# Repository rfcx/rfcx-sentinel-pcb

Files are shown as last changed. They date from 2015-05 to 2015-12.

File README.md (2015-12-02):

#RFCx Sentinel PCB
@gibsjose @jesse-millwood @rfcx

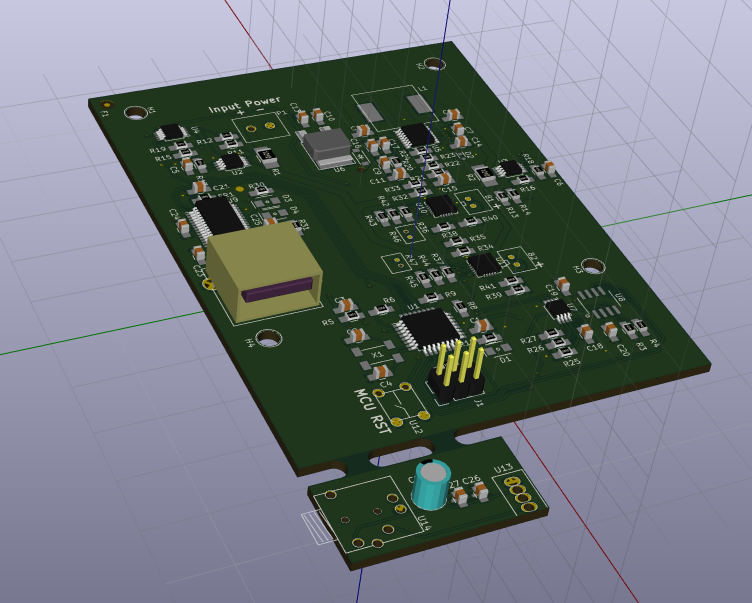
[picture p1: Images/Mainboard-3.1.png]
PCB


##Description
This repository contains the **KiCAD** project and related libraries for the RFCx PCB designed by Jesse Millwood and Joe Gibson for the GVSU (Grand Valley State University) RFCx Senior Project design, *Project Necromancer*. This project has been continued by Jesse Millwood and Joe Gibson after they graduated and has since been renamed *RFCx Sentinel*. 

This repository is for the main board that includes the following functionality:
- Buck/Boost input voltage to charge phone
- Regulate input power 3.3V to run the logic on the board
- Charge two Lithium Ion Batteries
- Take local measurements such as voltage, current, temperature, and humidity
- Relay information to the phone via a USB interface
- An experimental breakaway board for microphone filtering

This README is meant to be a user guide for the **REV 3** main board. 

###Revision Overview
Rev1 of the board was a single board and was designed for one particular off-the-shelf enclosure.
Rev2 of the design is a modular design in order to introduce a degree of flexibility to the design. This revision included an MPPT board and main board.
Rev3 of the design will keep the modular design, however new components will be chosen based on testing of Rev2. This revision is just the main board.

##Physical Install Instructions
The enclosure that is being used is the Polycase WP-33. The installer must take into consideration where the interfacing wires will be in relation to the other board. A list of interfacing wires that must be considered are:
* **Main Board:** Power from the panels.
* **Main Board:** 2 JST connectors that go from the batter charging circuitry to the batteries
* **Main Board:** 2 JST connectors that interface to the NTC thermocouple. This thermocouple is meant to be glued or attached to the batteries.
* **Main Board:** 1 USBA to microUSB connector to the phone
Once the hardware connections are made it will be a good idea to ensure that the phone has the proper software installed such as the proper ROM and version of the Gaurdian app. For phone software refer to the [RFCx Guardian App](https://github.com/rfcx/rfcx-guardian-android) github page.

##Outline of Directories
.  
├── Images  
│   ├── *Contains Images for the README*  
├── Kicad Project  
│   ├── Graphics  
│   │   ├── *Contains Graphics for the silk screen layer*  
│   ├── Graphics.pretty  
│   │   ├── *Contains `.kicad_mod` files to be placed on the silk screen layer*  
│   └── Main  
│       ├── *Contains schematic files (`.sch`) for the main board  
│       ├── Fabrication  
│       │   └── *Contains files for fabrication (Gerbers, BOM, Position, PDF)*  
│       │       Gerbers  
│       │       ├── *Contains Gerbers for the board manufacturers*  
│       │       Position  
│       │       ├── Inches  
│       │       │   ├── *Contains position file for top and bottom layers in inches*  
│       │       └── mm  
│       │           └── *Contains position file for top and bottom layers in mm*  
│       RFCx.pretty  
│       ├── *Contains module (footprint) files for components that needed to be made*  
│       Local-Libs  
│       └── *Contains schematic part libraries for parts that were made for this project*  
└── LICENSE  

## How to use this repository
1. Install KiCAD(4.0+) (http://kicad-pcb.org/download/)
2. clone the libraries and checkout a specific version
``` sh
mkdir -p ~/build
cd ~/build
git clone https://github.com/KiCad/kicad-library.git
cd kicad-library
git checkout 3c84dba8e473a325a17eae25ed3203d949589c10
mkdir build
cd build
cmake ..
make
make install
```
- A specific version of the KiCAD schematic libraries is used because sometimes they change. It is just safer to stick with one version though so there is little to no need to mess with the schematic symbols later
3. Download KiCAD footprints
4. Open the KiCAD application and load the project file.
- `File`-> `Open Project`
5. Open the `Mainboard.sch` file.
6. Tell KiCAD where the schematic symbol libraries are
- `Preferences`->`Component Libraries`
- Click the lower `Add` button and search for the `Local-Libs` directory if not already listed in the bottom pane of the window.
- Click the upper `Add` button and change to the `Local-Libs` directory. Select all of the `.lib` files and hit `Open`
- Click `Okay`

## Conventions for this project
- **Schematic Libraries:** The symbols in the `Local-Libs` libraries are to be used first. This is because I like how these symbols look. If the symbol is not there, use the symbols in `kicad-library`. If the symbol you are looking for isn't in any of those, make it your self, add it to the `Local-Libs` and make not of it in a pull request.
- **Footprint Libraries:** 
- **PCB Canvas:** Editing of the PCB should be done in the GAL mode of `pcbnew`. This is because some things are handled slightly differently in the other canvases.
- **
- **Units:** Use Imperial units when editing/laying out so an object/trace is not located at some odd fraction of an inch.

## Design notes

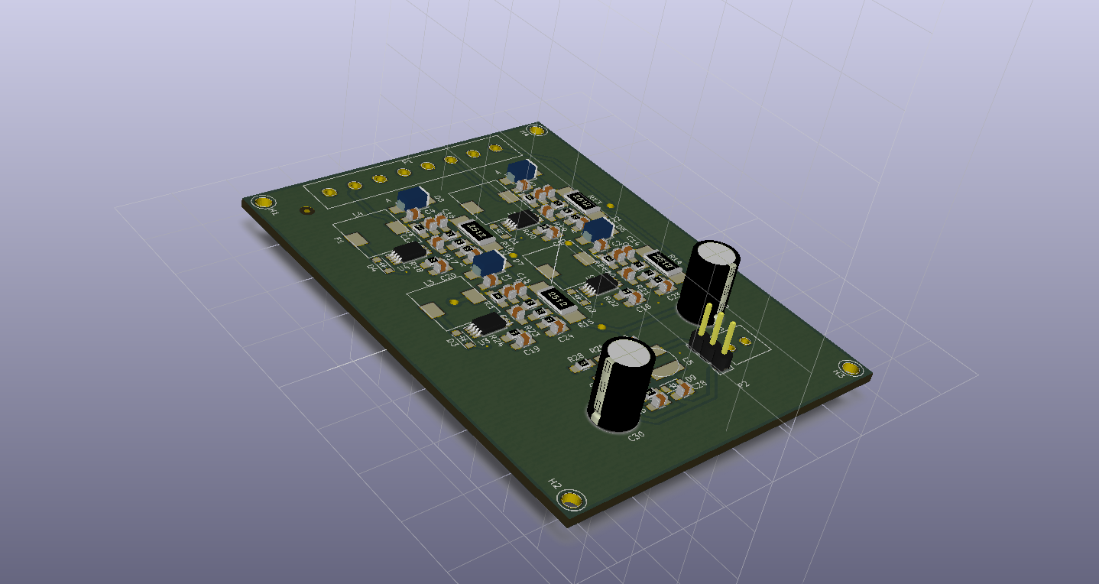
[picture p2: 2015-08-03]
Images/MPPTboard_top.png

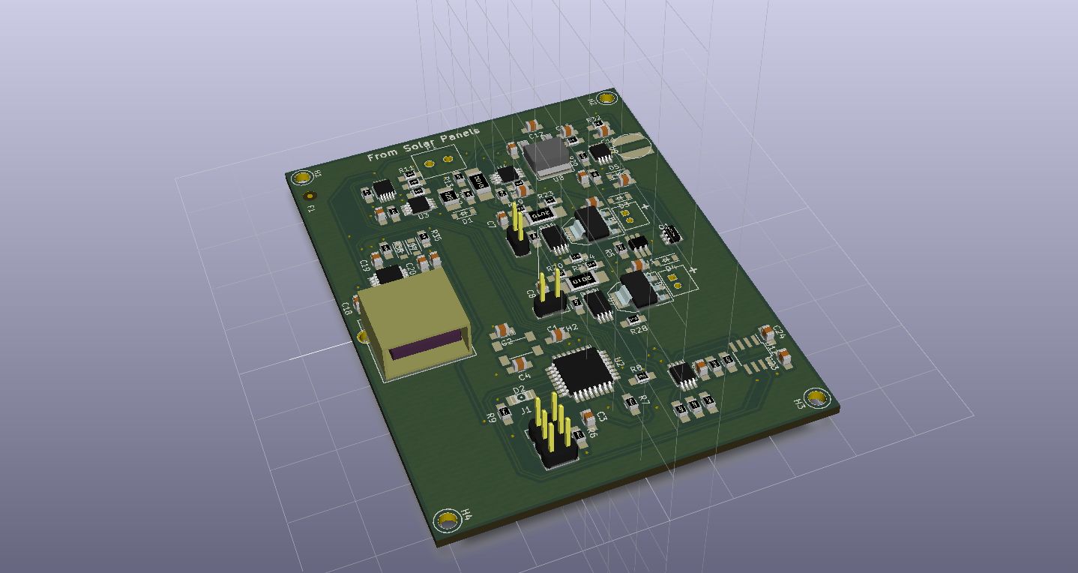
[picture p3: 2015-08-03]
Images/Mainboard_top.png

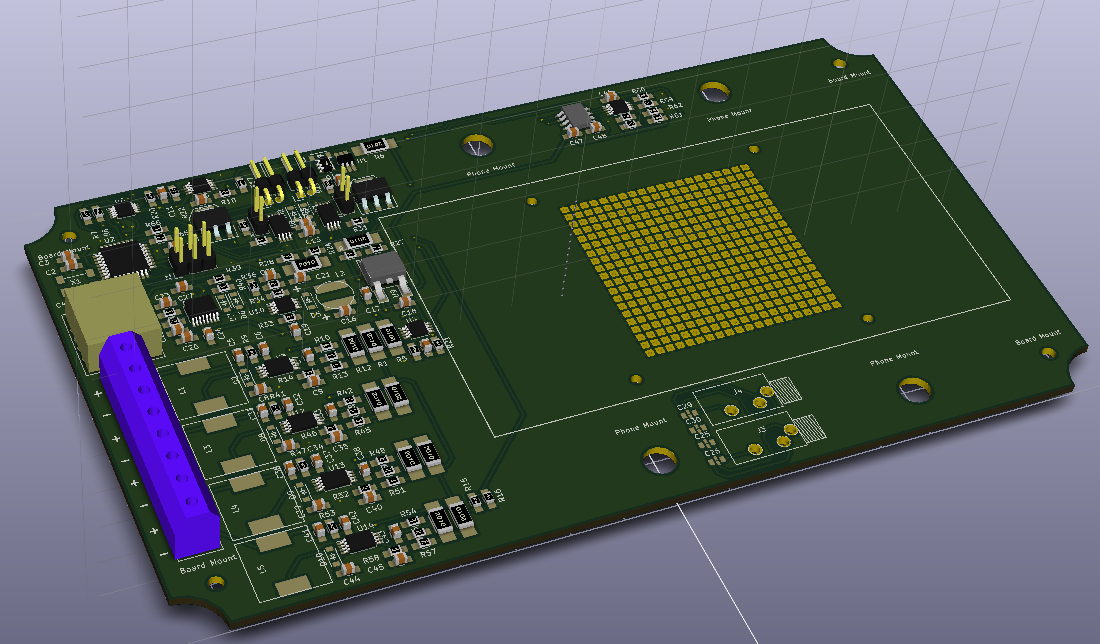
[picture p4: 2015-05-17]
Images/angle.png

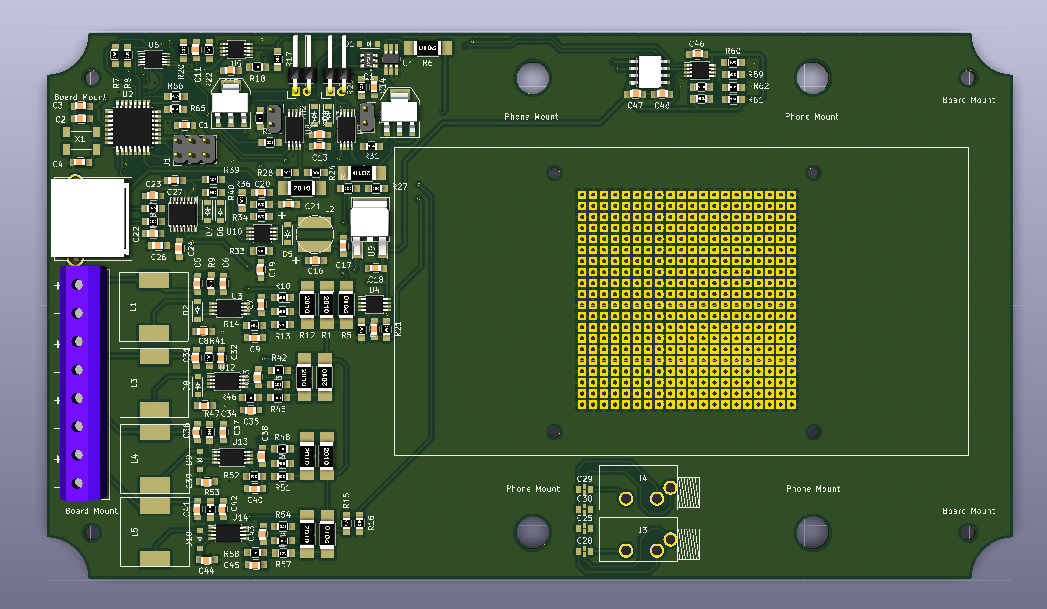
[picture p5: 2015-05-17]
Images/top.png

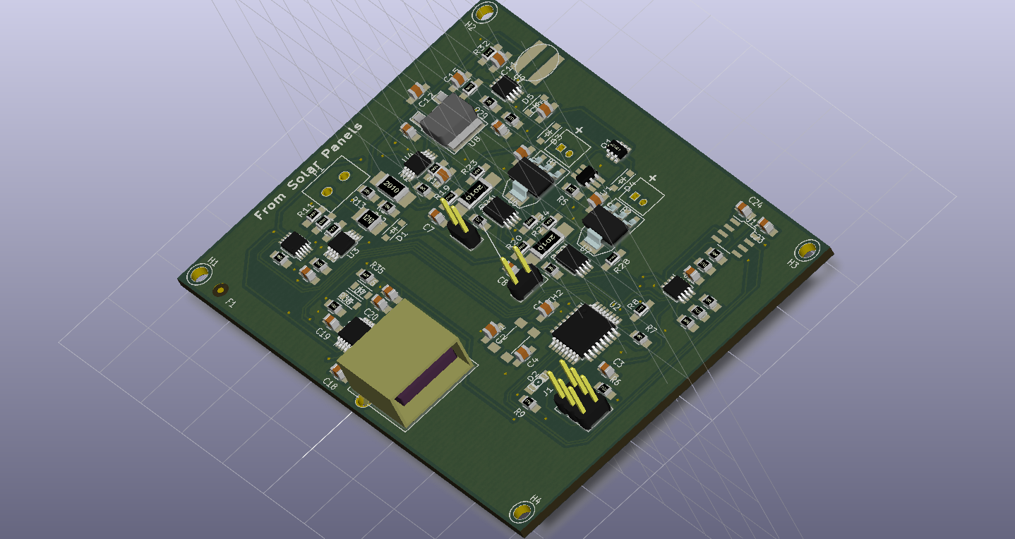
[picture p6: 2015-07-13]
Images/Mainboard.png

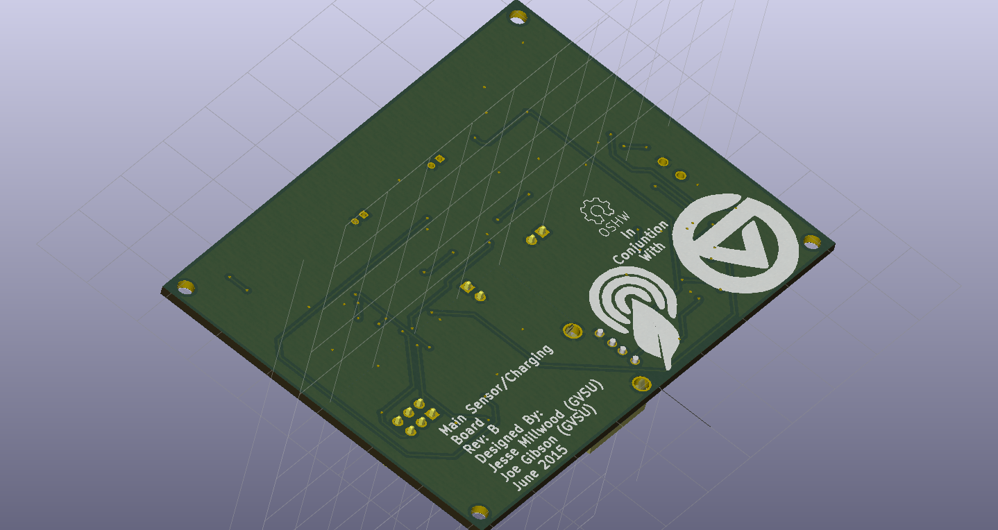
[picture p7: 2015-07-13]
Images/Mainboard_B.png

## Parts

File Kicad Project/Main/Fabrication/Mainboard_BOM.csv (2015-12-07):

Project: | Mainboard
Tool: | kicad
Number of Parts | 91
Reference | Quantity | Value | Package | Distributor | Distributor #
F1 | 1 | Fiducial | Fiducials:Fiducial_1mm_Dia_2.54mm_Outer_CopperTop | DigiKey | NA
C26,C27 | 2 | Cap-X2Y | RFCx:C_0805_X2Y | DigiKey | 709-1010-1-ND
C28 | 1 | DNP | Capacitors_ThroughHole:C_Radial_D5_L6_P2.5 | DigiKey | NA
C2,C4 | 2 | 6pF | Capacitors_SMD:C_0805_HandSoldering | DigiKey | 311-1095-1-ND
C23,C22 | 2 | 47pF | Capacitors_SMD:C_0805_HandSoldering | DigiKey | 1276-1832-1-ND
C5,C6,C20,C18,C24,C21,C25 | 7 | 0.1uF | Capacitors_SMD:C_0805_HandSoldering | DigiKey | 399-1167-1-ND
C19 | 1 | 0.22uF | Capacitors_SMD:C_0805_HandSoldering | DigiKey | 587-1287-1-ND
C3,C1,C13,C10 | 4 | 1uF | Capacitors_SMD:C_0805_HandSoldering | DigiKey | 1276-1275-1-ND
U14 | 1 | 3.5mm-Female-TH | RFCx:Audio_3.5mm_Feale_TH | DigiKey | CP-435107-ND
FR1 | 1 | Ferrite | Resistors_SMD:R_0805_HandSoldering | DigiKey | 587-1911-1-ND
R46,R47 | 2 | NTC | RFCx:JST-1.5mm | DigiKey | BC2384-ND, 455-1657-ND
R2,R1 | 2 | 0.51, 1W | Resistors_SMD:R_1210_HandSoldering | DigiKey | RCWE.51FCT-ND
R29,R28 | 2 | 27 | Resistors_SMD:R_0805_HandSoldering | DigiKey | P27ACT-ND
R30,R31 | 2 | 270 | Resistors_SMD:R_0805_HandSoldering | DigiKey | 311-270CRCT-ND
R10 | 1 | 730 | Resistors_SMD:R_0805_HandSoldering | DigiKey | P732CCT-ND
R8,R9,R7,R6,R36,R42,R37,R44 | 8 | 1k | Resistors_SMD:R_0805_HandSoldering | DigiKey | P1.0KACT-ND
R40,R41 | 2 | 1.14k | Resistors_SMD:R_0805_HandSoldering | DigiKey | P1.15KCCT-ND
R11,R13 | 2 | 1540 | Resistors_SMD:R_0805_HandSoldering | DigiKey | P1.54KCCT-ND
R12,R14 | 2 | 2100 | Resistors_SMD:R_0805_HandSoldering | DigiKey | P2.10KCCT-ND
R17,R18 | 2 | 2550 | Resistors_SMD:R_0805_HandSoldering | DigiKey | 311-2.55KCRCT-ND
R3,R4 | 2 | 4.7k | Resistors_SMD:R_0805_HandSoldering | DigiKey | 311-4.70KCRCT-ND
R5,R19,R25,R26,R27,R43,R45 | 7 | 10k | Resistors_SMD:R_0805_HandSoldering | DigiKey | P10KACT-ND
R38,R33,R39,R35 | 4 | 100k | Resistors_SMD:R_0805_HandSoldering | DigiKey | RHM100KCHCT-ND
R15,R16 | 2 | 200k | Resistors_SMD:R_0805_HandSoldering | DigiKey | P200KACT-ND
R32,R34 | 2 | 270k | Resistors_SMD:R_0805_HandSoldering | DigiKey | P270KCCT-ND
H1,H2,H3,H4 | 4 | Mounting_Hole | RFCX:Mnt_Hole | DigiKey | NA
U13 | 1 | 3.5mm-Male-TH | RFCx:Audio_3.5mm_Male_TH | DigiKey | 839-1239-ND
D1 | 1 | LED | RFCx:LED-1208 | DigiKey | 160-1404-1-ND
D5 | 1 | RB161M-20 | Diodes_SMD:SOD-123 | DigiKey | RB161M-20CT-ND
D3 | 1 | GRN | RFCx:LED-1208 | DigiKey | 350-2885-ND
D4 | 1 | YLW | RFCx:LED-1208 | DigiKey | 511-1275-1-ND
P1 | 1 | CONN_01X02 | RFCX:TerminalBlock_2 | DigiKey | ED2740-ND
U1 | 1 | ATmega328P | Housings_QFP:TQFP-32_7x7mm_Pitch0.8mm | DigiKey | ATMEGA328P-AU-ND
J1 | 1 | ICSP | Pin_Headers:Pin_Header_Straight_2x03 | DigiKey | S2011EC-03-ND
U12 | 1 | Button_SPST_4 | RFCx:SPST_4 | DigiKey | 450-1650-ND
U2,U3 | 2 | LTC6800 | Housings_SSOP:MSOP-8_3x3mm_Pitch0.65mm | DigiKey | LTC6800HMS8#PBF-ND
U4 | 1 | ADS1015 | Housings_SSOP:MSOP-10_3x3mm_Pitch0.5mm | DigiKey | 296-25227-1-ND
U6 | 1 | SM72238 | TO_SOT_Packages_SMD:TO-252-2Lead | DigiKey | 296-39811-5-ND
U5 | 1 | DC-DC_Boost_Module | RFCx:DC-DC_Boost_Module | DigiKey | NA
U7 | 1 | LM75BDP | Housings_SSOP:MSOP-8_3x3mm_Pitch0.65mm | DigiKey | 568-4768-1-ND
U8 | 1 | HIH6130 | RFCx:HIH-SOIC-8 | DigiKey | 480-3651-1-ND
P2 | 1 | USB_A | Connect:USB_A | DigiKey | UE27AC54100-ND
U9 | 1 | FT232R | Housings_SSOP:SSOP-28_5.3x10.2mm_Pitch0.65mm | DigiKey | 768-1007-1-ND
U10,U11 | 2 | MCP73871 | Housings_DFN_QFN:QFN-20-1EP_4x4mm_Pitch0.5mm | DigiKey | MCP73871-2CCI/ML-ND
B1,B2 | 2 | Li-ion-2Cell-Conn | RFCx:JST-2mm | DigiKey | 455-1704-ND
X1 | 1 | 32kHz | RFCX:SOJ-4 | DigiKey | 300-8744-1-ND

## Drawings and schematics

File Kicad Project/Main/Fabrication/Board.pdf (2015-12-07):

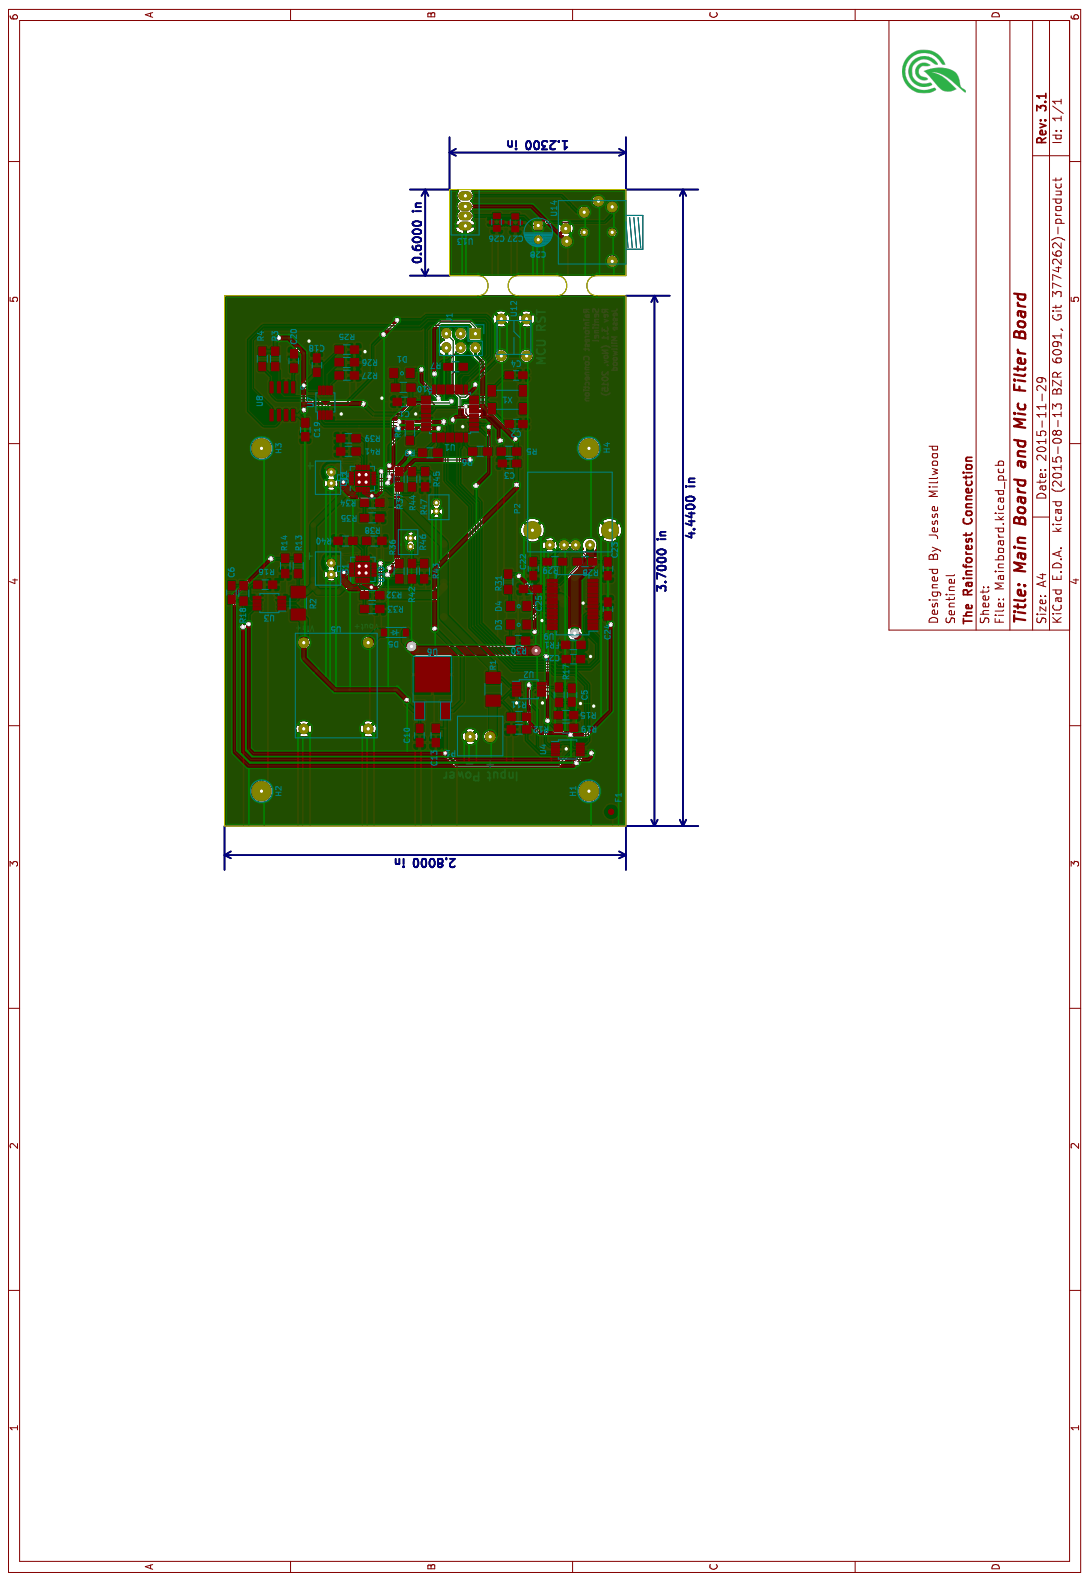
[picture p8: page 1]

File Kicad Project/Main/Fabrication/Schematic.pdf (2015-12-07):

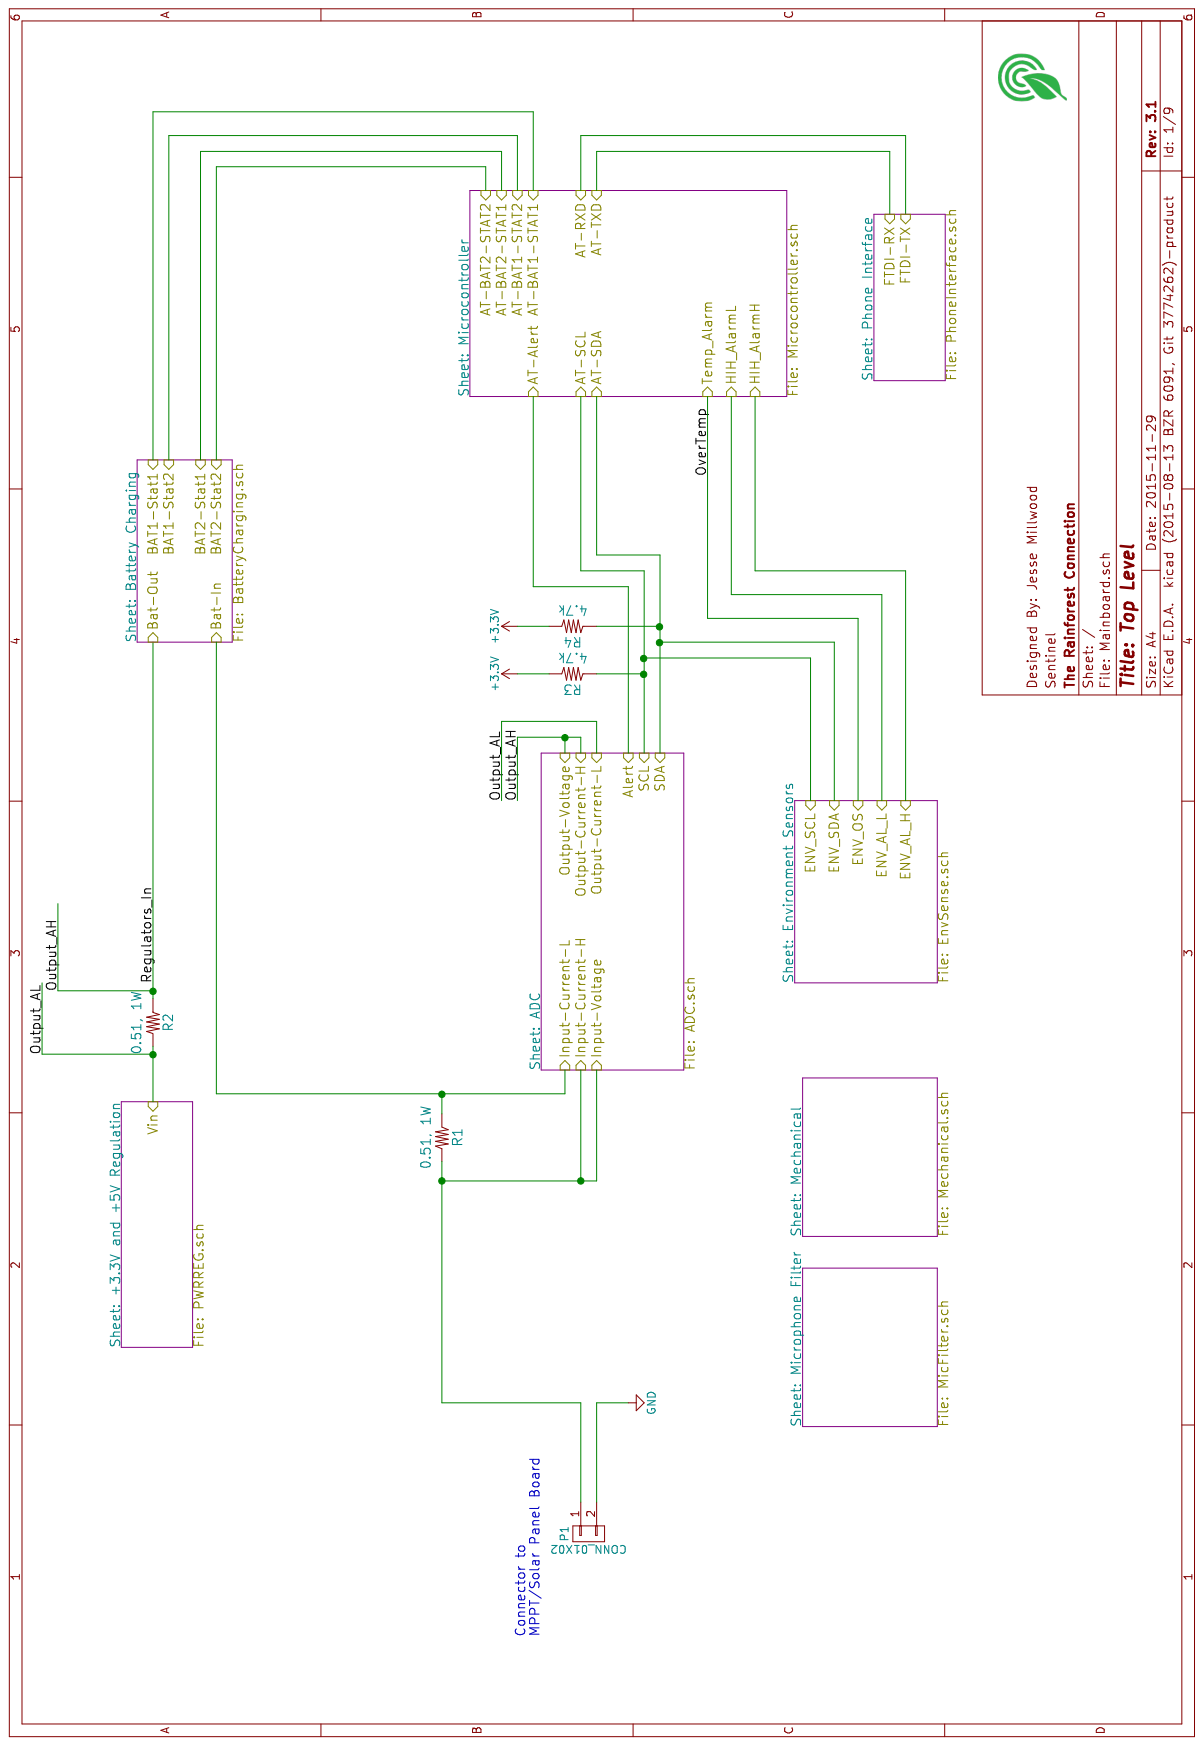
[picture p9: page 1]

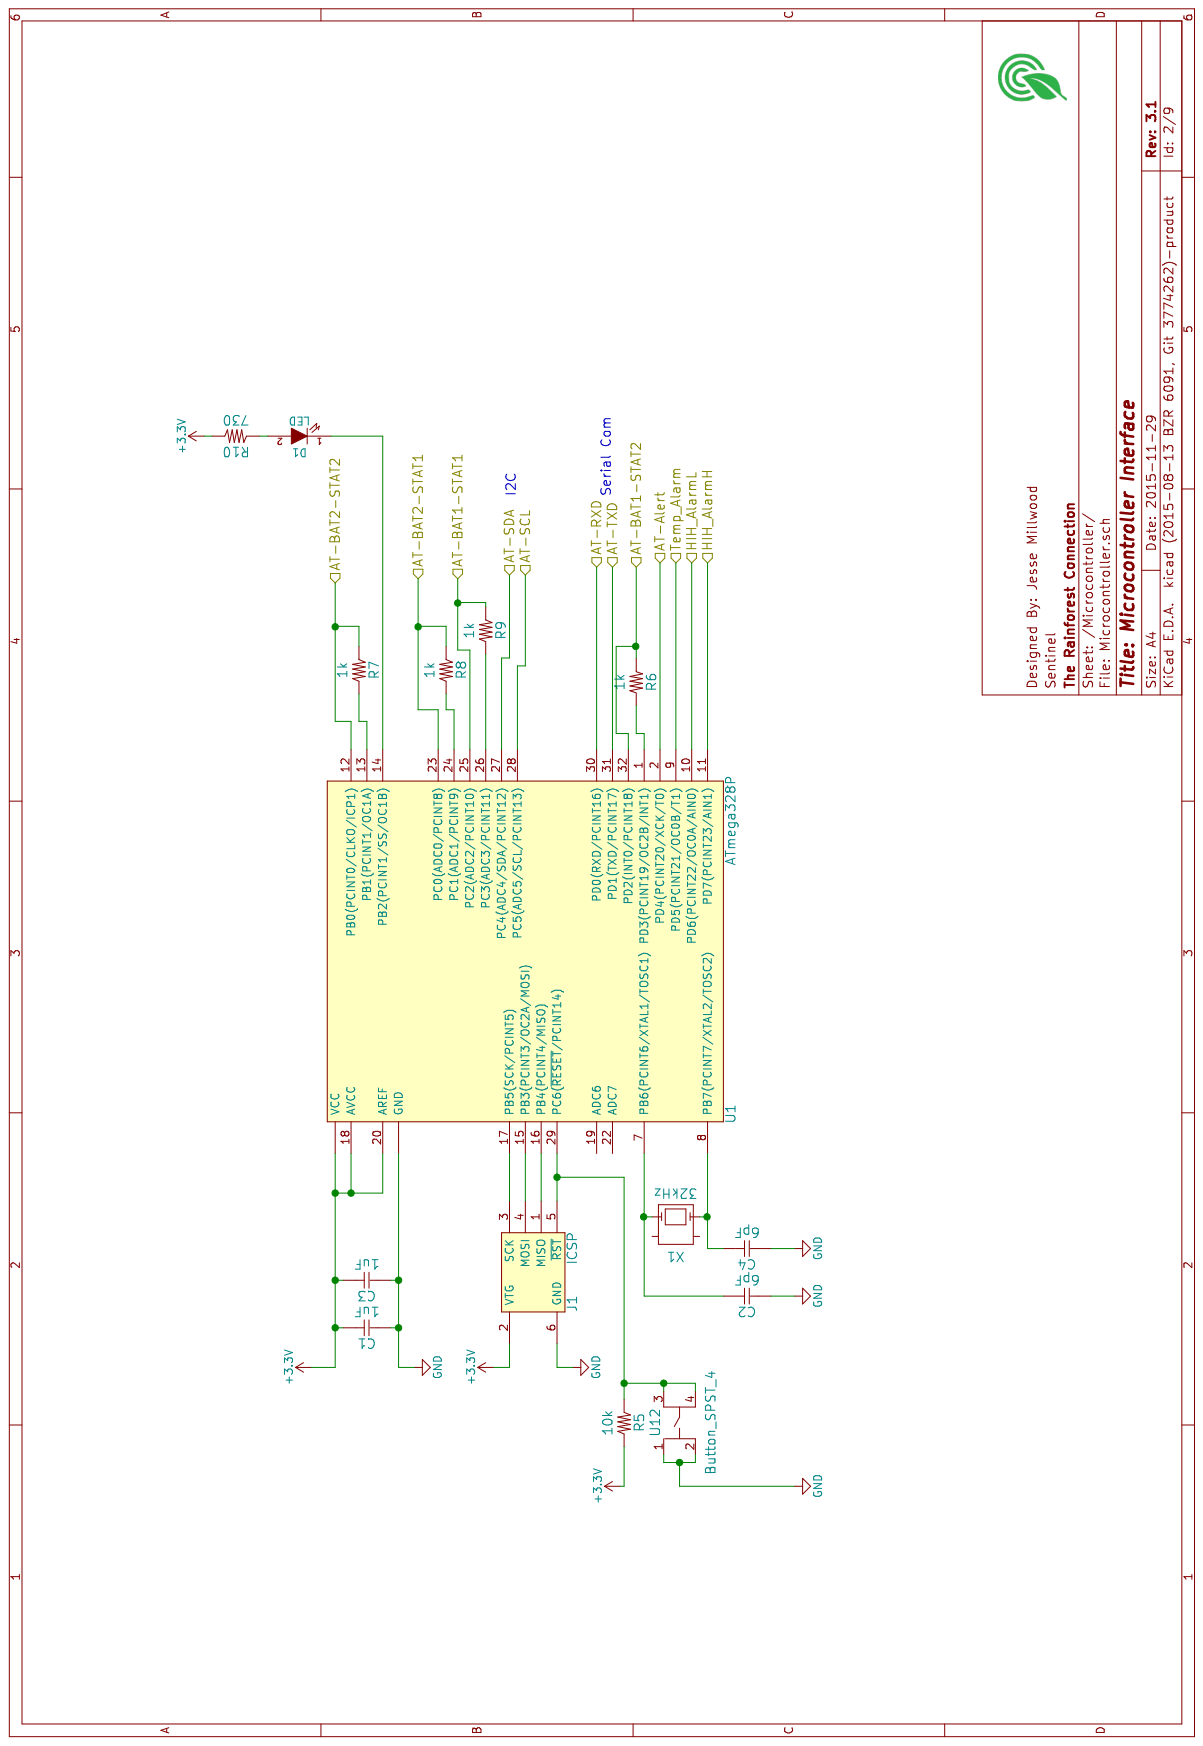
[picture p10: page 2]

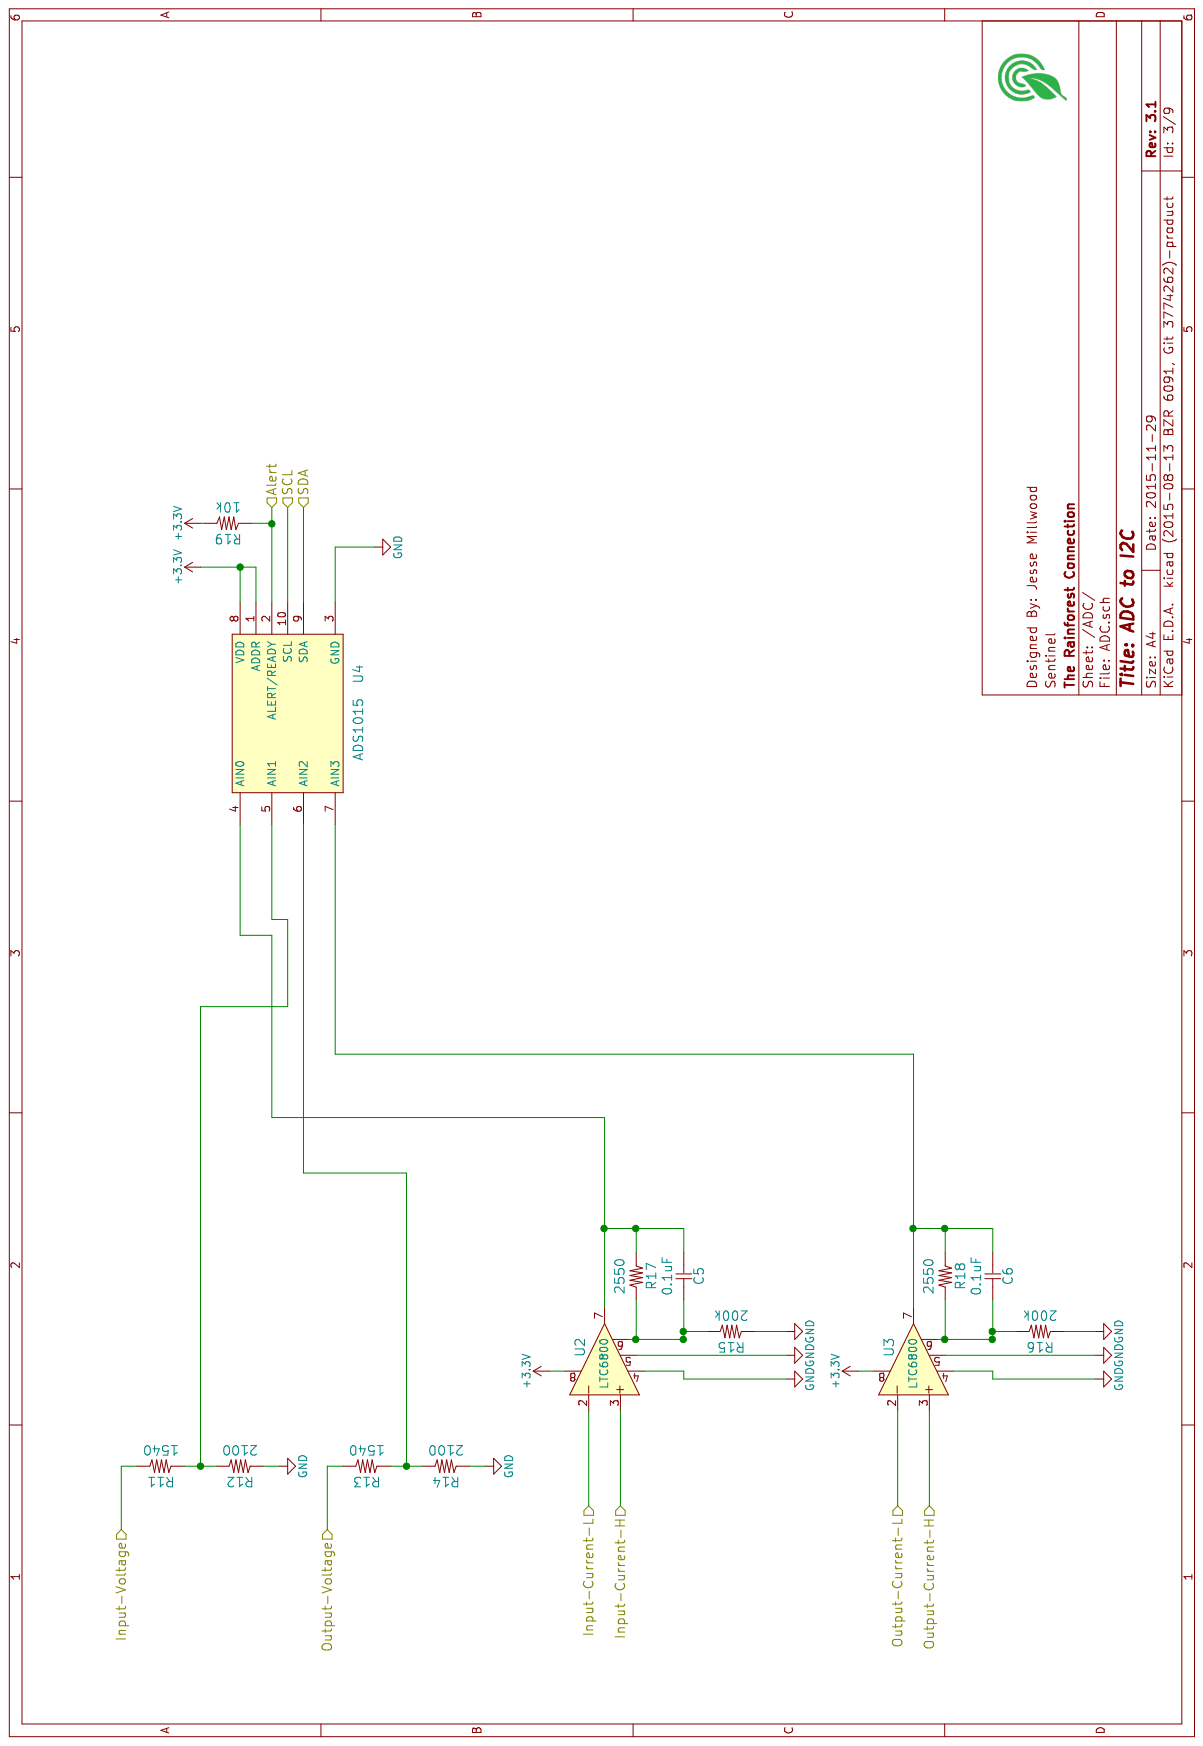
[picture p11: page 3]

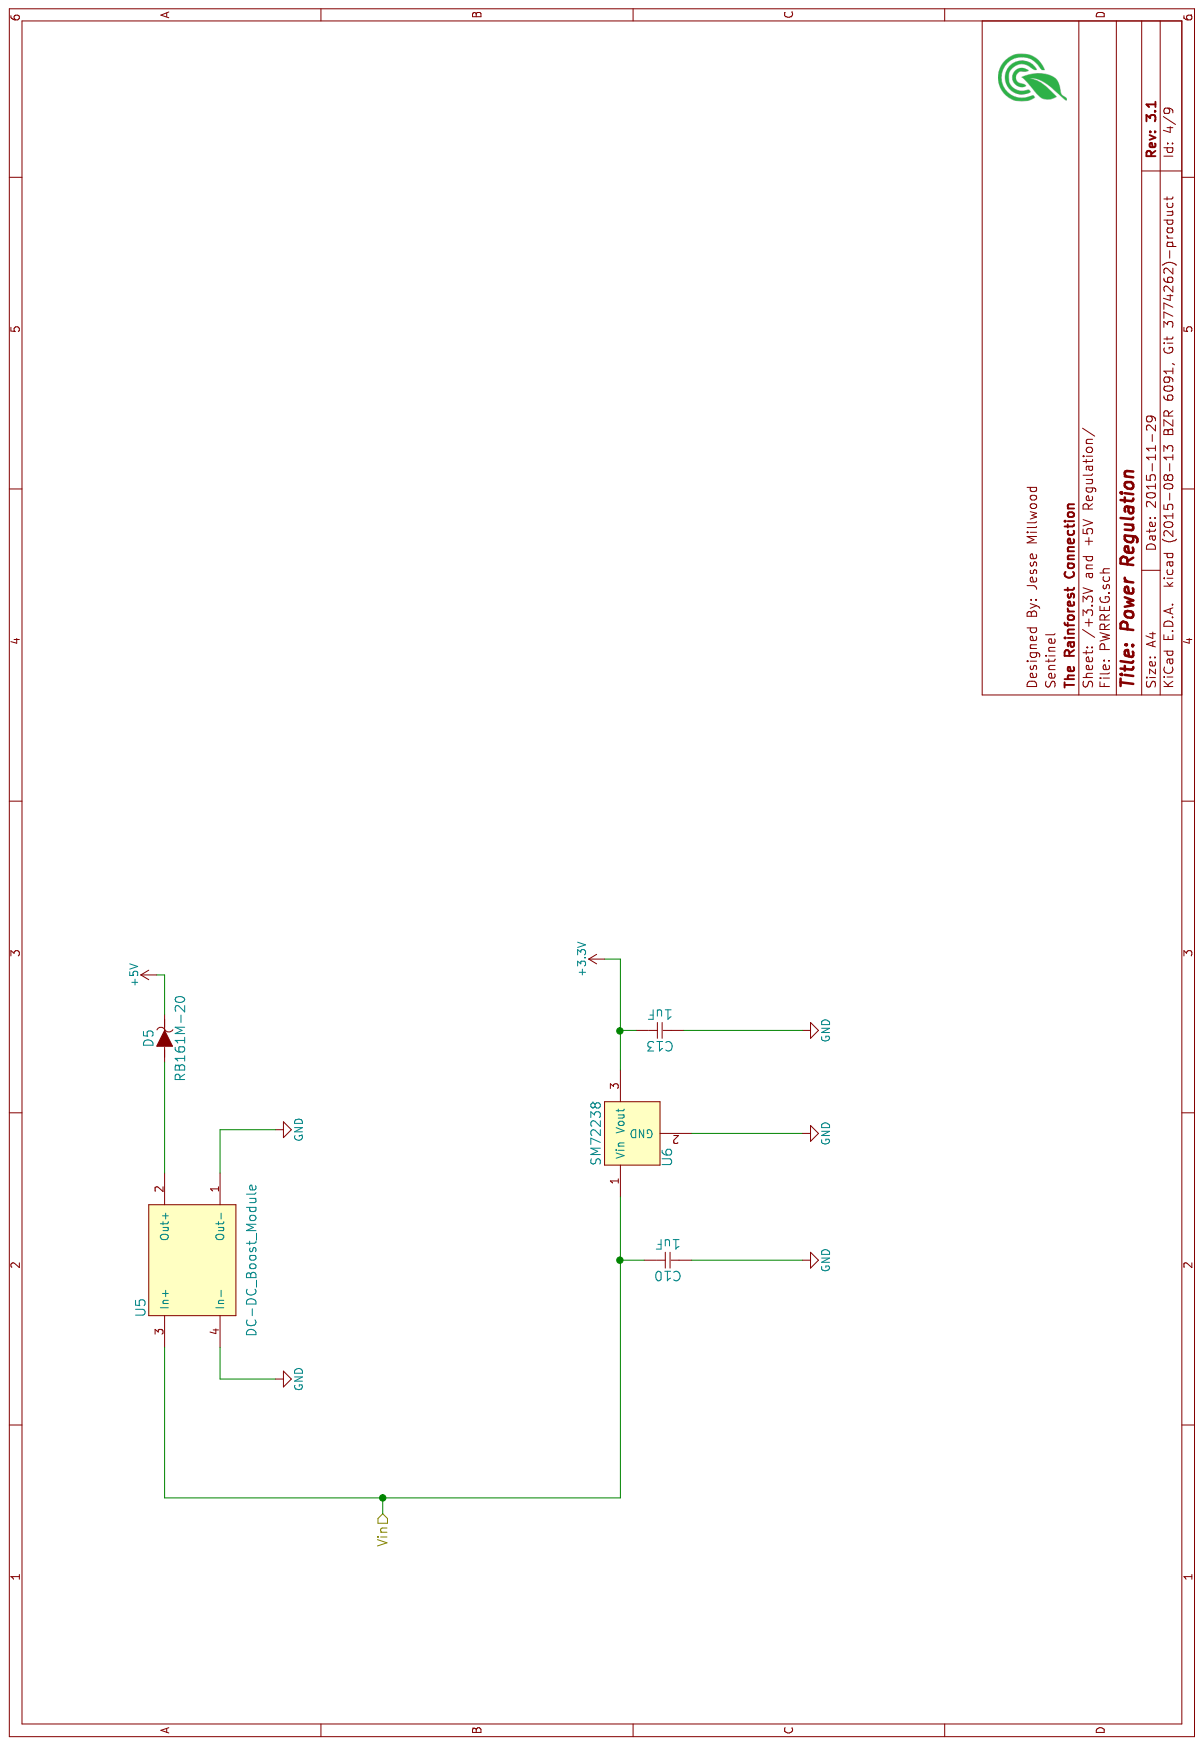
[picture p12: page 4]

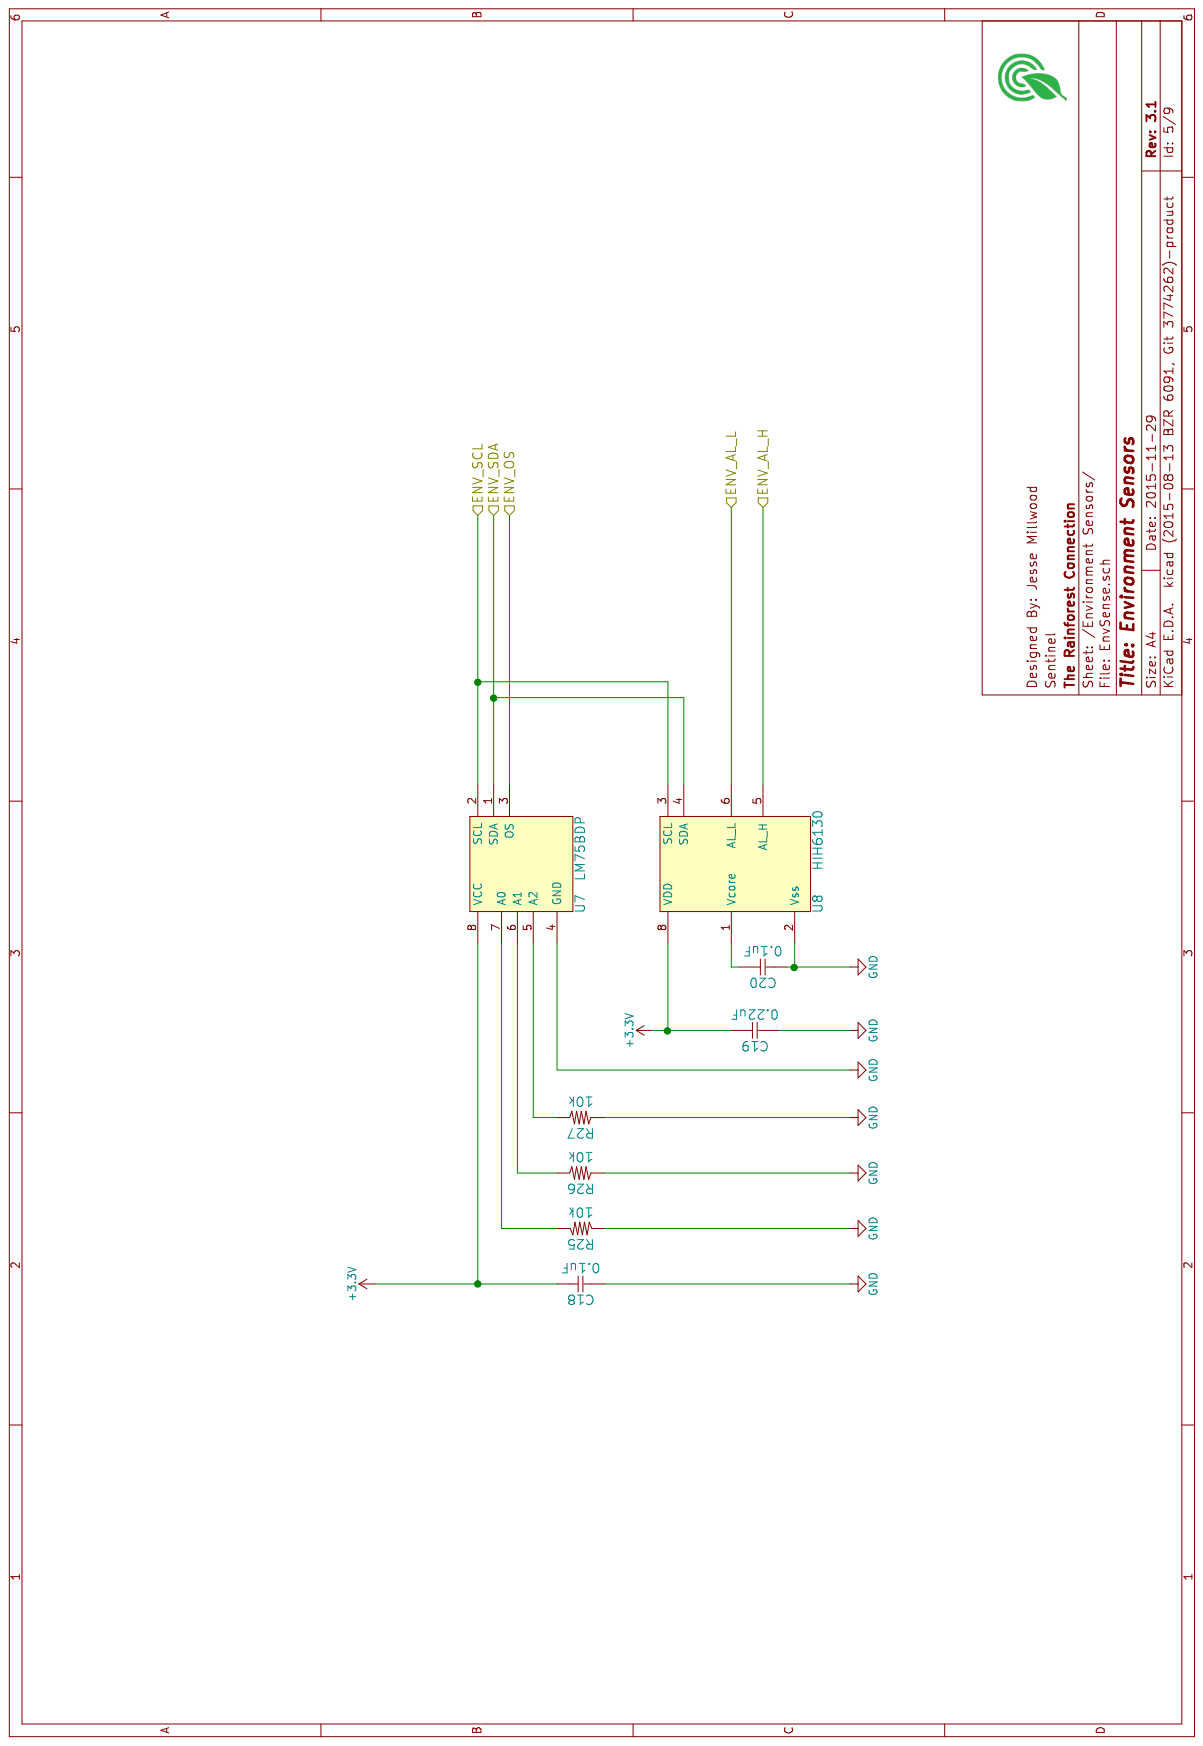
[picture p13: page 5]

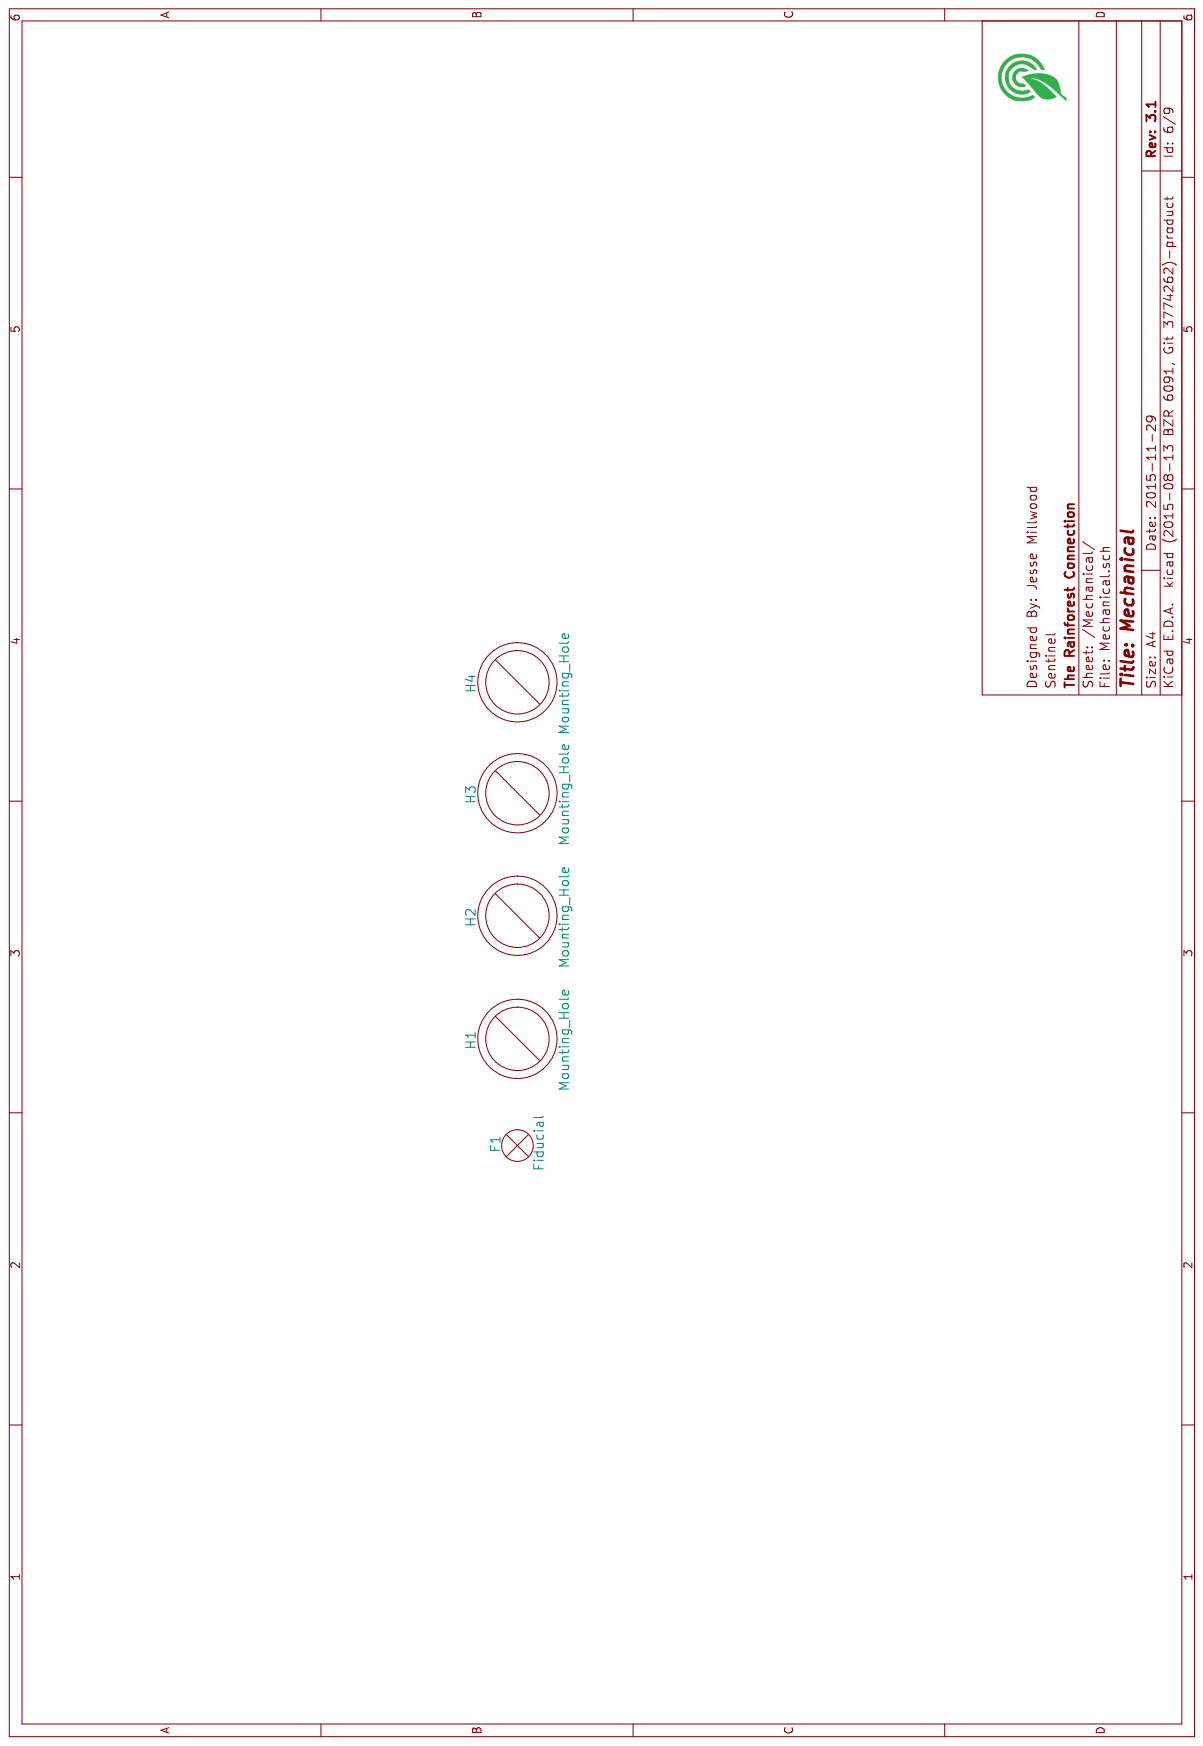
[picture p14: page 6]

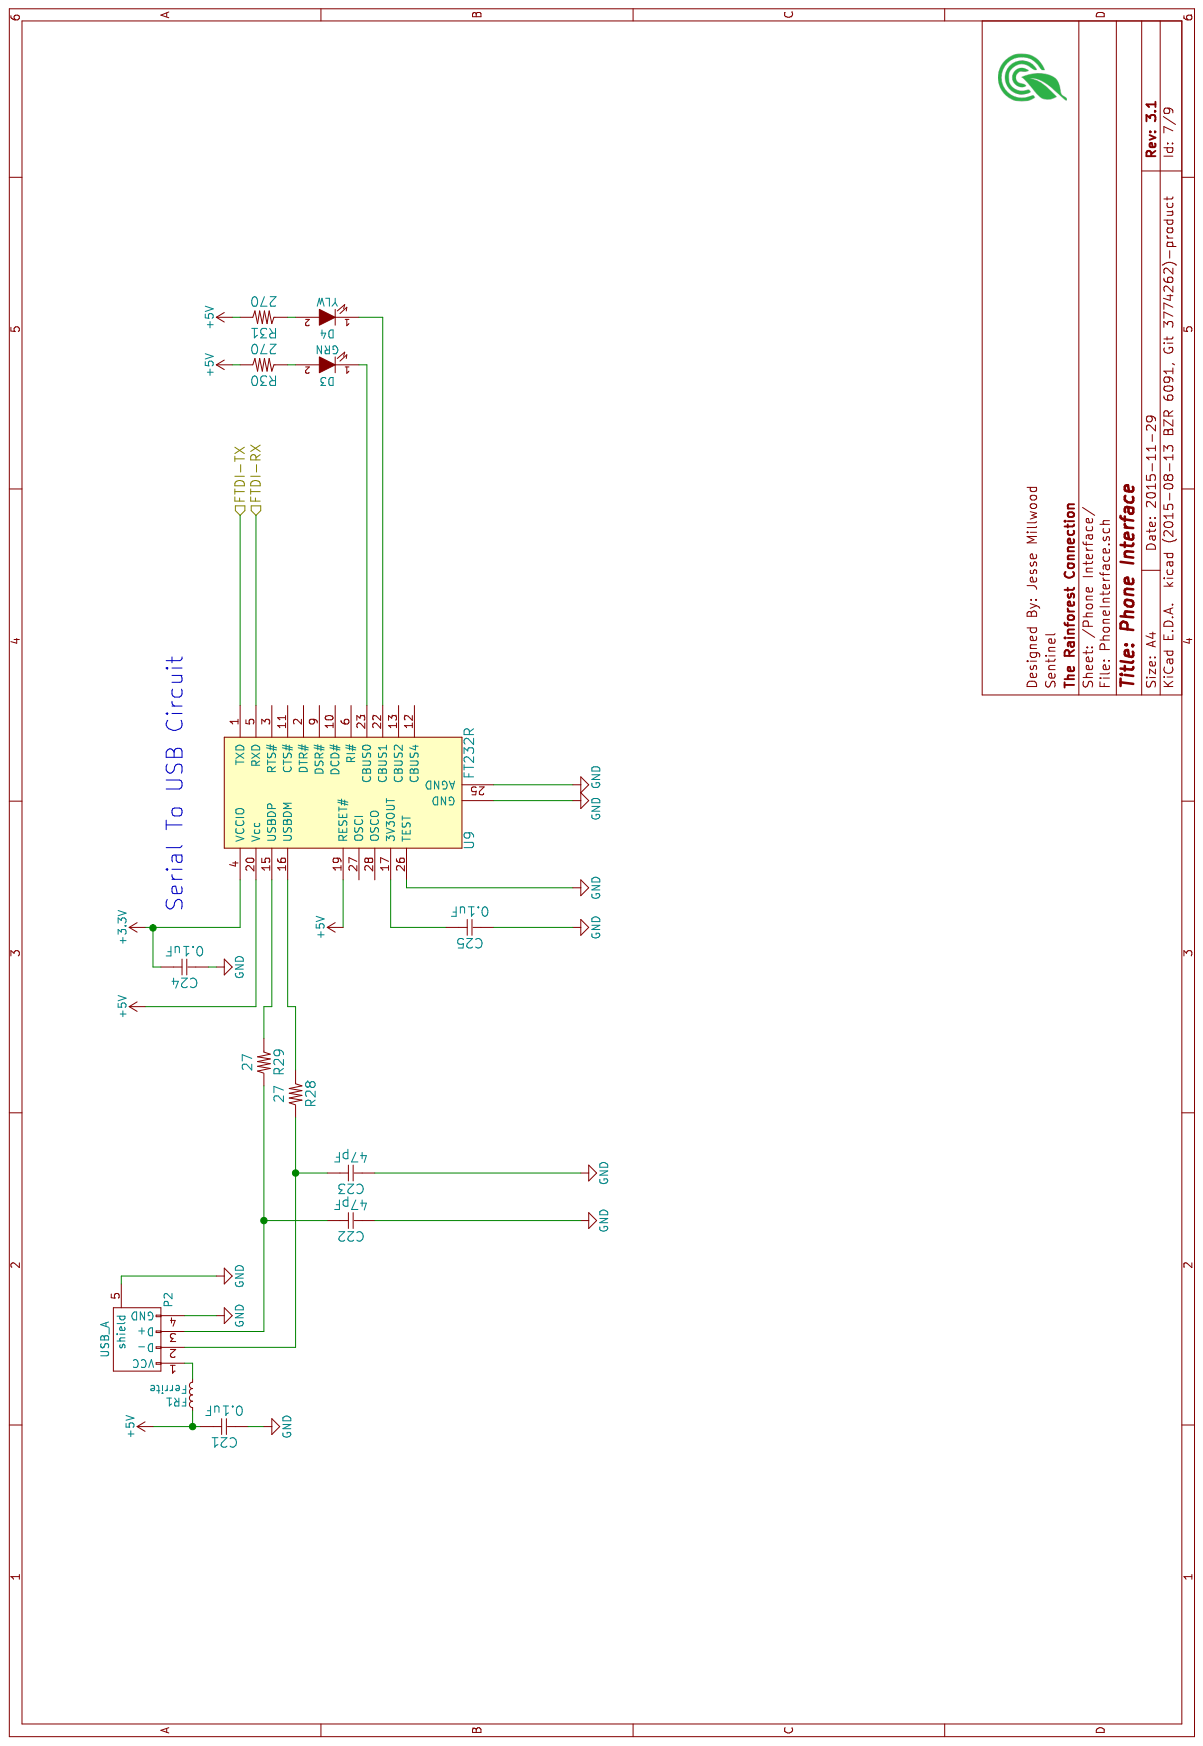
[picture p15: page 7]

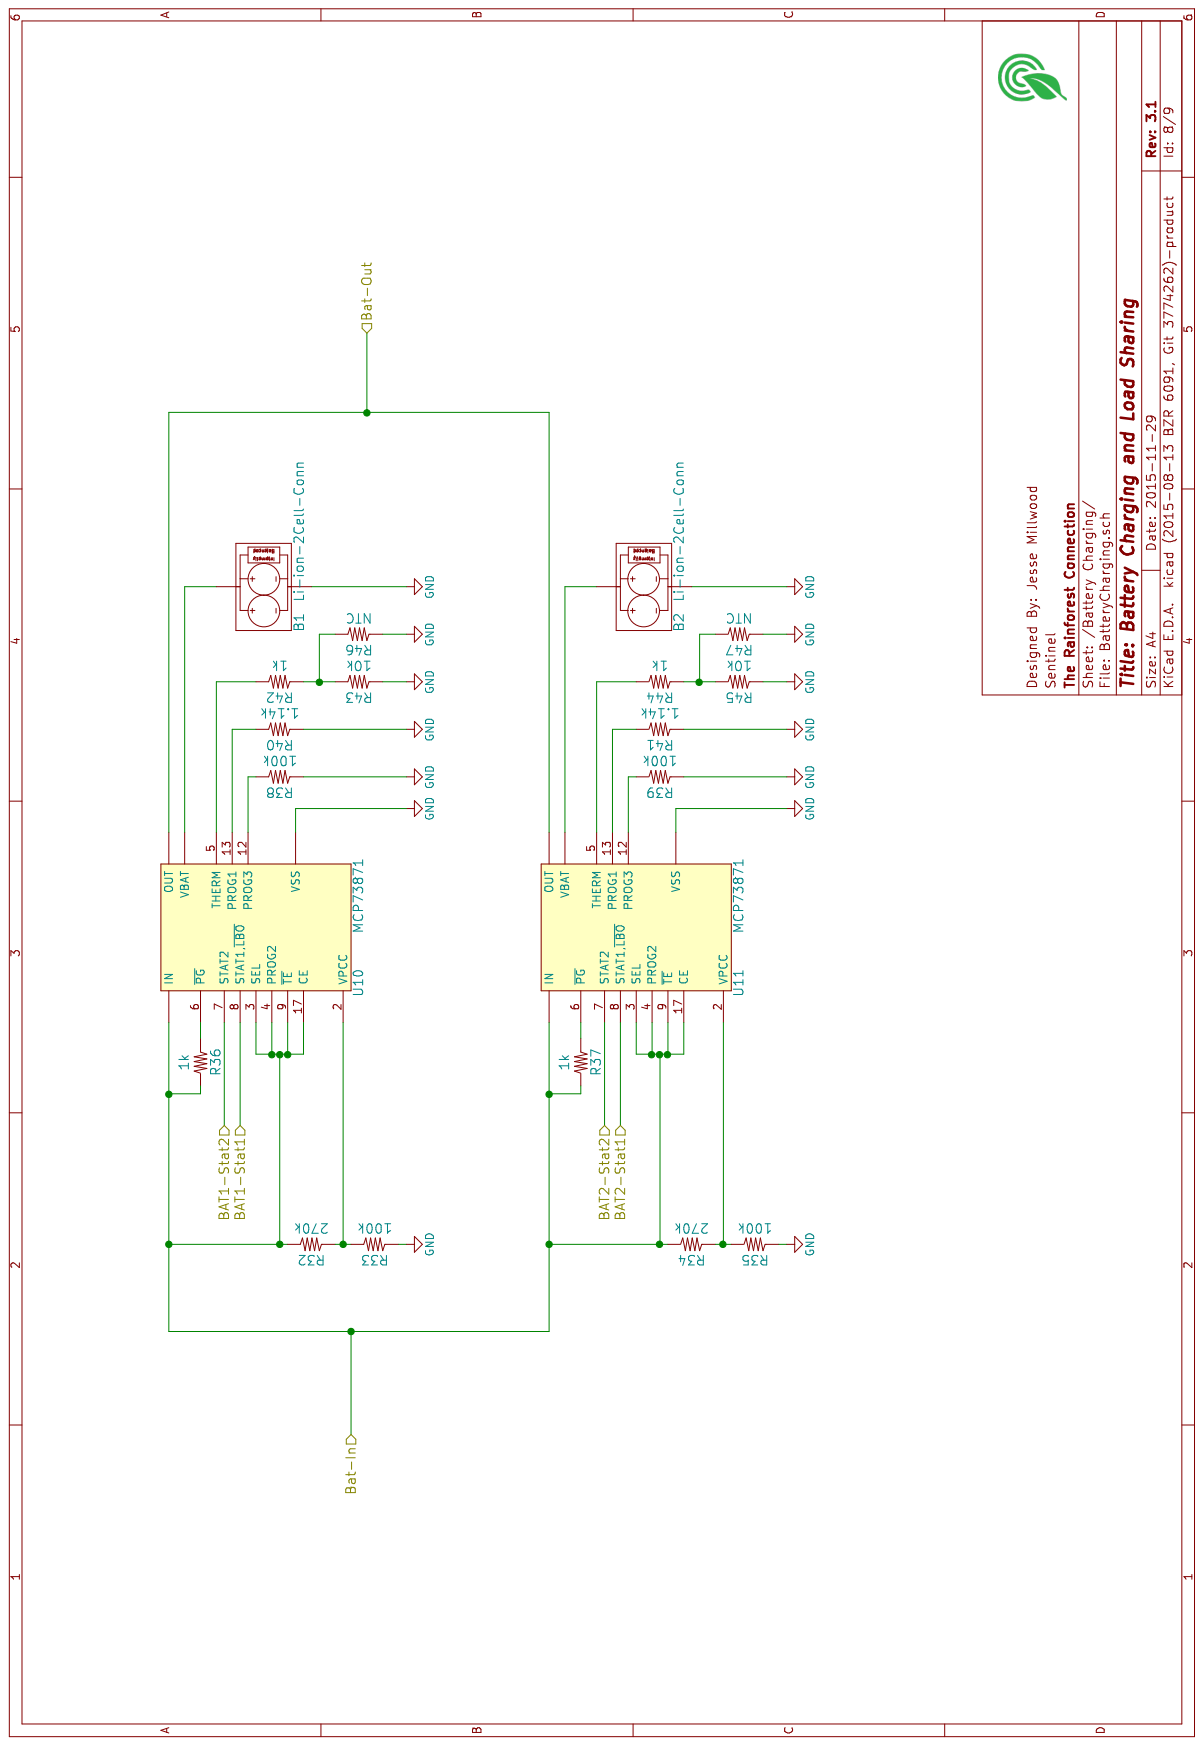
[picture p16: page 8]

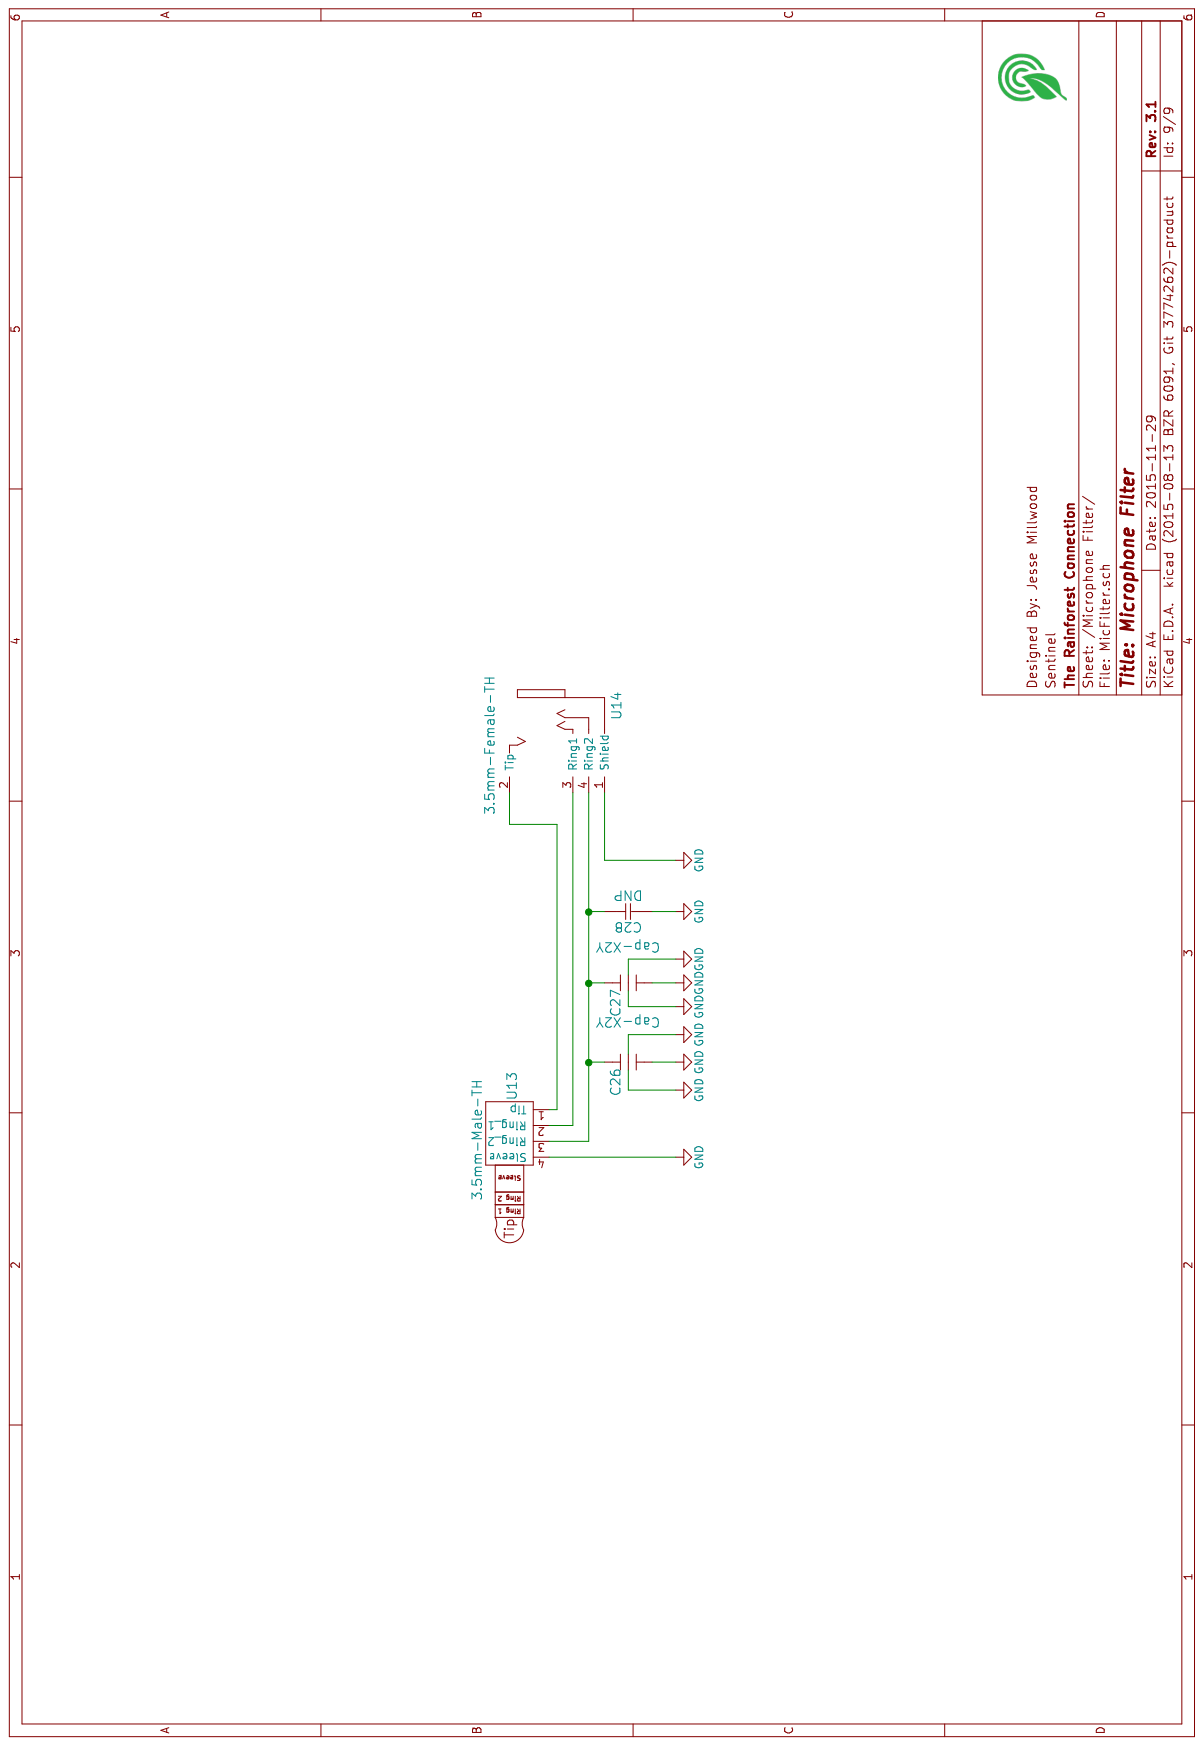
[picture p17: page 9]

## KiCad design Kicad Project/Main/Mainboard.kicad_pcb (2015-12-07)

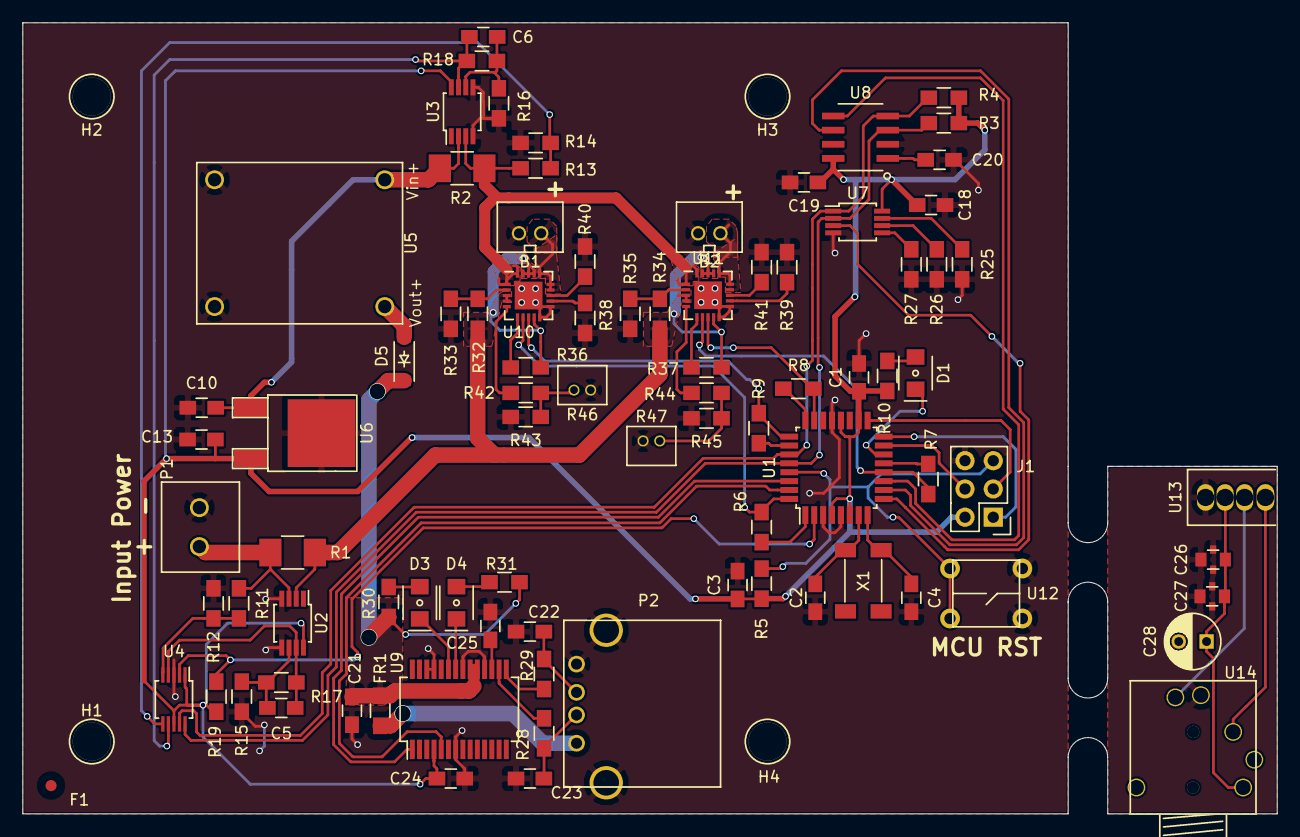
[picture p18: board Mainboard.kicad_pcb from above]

Board: 2 copper layers, 112.8 x 71.1 mm, 91 parts (0 on the bottom side), 69 nets.

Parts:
B1, B2: Li-ion-2Cell-Conn; JST-2mm
C1, C3, C10, C13: 1uF; C_0805_HandSoldering
C2, C4: 6pF; C_0805_HandSoldering
C5, C6, C18, C20, C21, C24, C25: 0.1uF; C_0805_HandSoldering
C19: 0.22uF; C_0805_HandSoldering
C22, C23: 47pF; C_0805_HandSoldering
C26, C27: Cap-X2Y; C_0805_X2Y
C28: DNP; C_Radial_D5_L6_P2.5
D1: LED; LED-1208
D3: GRN; LED-1208
D4: YLW; LED-1208
D5: RB161M-20; SOD-123
F1: Fiducial; Fiducial_1mm_Dia_2.54mm_Outer_CopperTop
FR1: Ferrite; R_0805_HandSoldering
H1, H2, H3, H4: Mounting_Hole; Mnt_Hole
J1: ICSP; Pin_Header_Straight_2x03
P1: CONN_01X02; TerminalBlock_2
P2: USB_A
R1, R2: 0.51, 1W; R_1210_HandSoldering
R3, R4: 4.7k; R_0805_HandSoldering
R5, R19, R25, R26, R27, R43, R45: 10k; R_0805_HandSoldering
R6, R7, R8, R9, R36, R37, R42, R44: 1k; R_0805_HandSoldering
R10: 730; R_0805_HandSoldering
R11, R13: 1540; R_0805_HandSoldering
R12, R14: 2100; R_0805_HandSoldering
R15, R16: 200k; R_0805_HandSoldering
R17, R18: 2550; R_0805_HandSoldering
R28, R29: 27; R_0805_HandSoldering
R30, R31: 270; R_0805_HandSoldering
R32, R34: 270k; R_0805_HandSoldering
R33, R35, R38, R39: 100k; R_0805_HandSoldering
R40, R41: 1.14k; R_0805_HandSoldering
R46, R47: NTC; JST-1.5mm
U1: ATmega328P; TQFP-32_7x7mm_Pitch0.8mm
U2, U3: LTC6800; MSOP-8_3x3mm_Pitch0.65mm
U4: ADS1015; MSOP-10_3x3mm_Pitch0.5mm
U5: DC-DC_Boost_Module
U6: SM72238; TO-252-2Lead
U7: LM75BDP; MSOP-8_3x3mm_Pitch0.65mm
U8: HIH6130; HIH-SOIC-8
U9: FT232R; SSOP-28_5.3x10.2mm_Pitch0.65mm
U10, U11: MCP73871; QFN-20-1EP_4x4mm_Pitch0.5mm
U12: Button_SPST_4; SPST_4
U13: 3.5mm-Male-TH; Audio_3.5mm_Male_TH
U14: 3.5mm-Female-TH; Audio_3.5mm_Feale_TH
X1: 32kHz; SOJ-4

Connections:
+3V3: C1.1, C3.1, C13.1, C18.1, C19.1, C24.1, J1.2, R3.1, R4.1, R5.1, R10.1, R19.1, U1.4, U1.6, U1.18, U1.20, U2.8, U3.8, U4.1, U4.8, U6.3, U7.8, U8.8, U9.4
+5V: C21.1, D5.1, FR1.1, R30.1, R31.1, U9.19, U9.20
/ADC/Input-Current-H: P1.1, R1.1, R11.1, U2.3
/ADC/Output-Current-L: C10.1, R2.1, U3.2, U5.3, U6.1
/Battery Charging/Bat-In: R1.2, R32.1, R34.1, R36.1, R37.1, U2.2, U10.3, U10.4, U10.9, U10.17, U10.18, U10.19, U11.3, U11.4, U11.9, U11.17, U11.18, U11.19
/Battery Charging/Bat-Out: R2.2, R13.1, U3.3, U10.1, U10.20, U11.1, U11.20
/Environment Sensors/ENV_AL_H: U1.11, U8.5
/Environment Sensors/ENV_AL_L: U1.10, U8.6
/Environment Sensors/ENV_OS: U1.9, U7.3
/Microcontroller/AT-Alert: R19.2, U1.2, U4.2
/Microcontroller/AT-BAT1-STAT1: R9.2, U1.25, U10.8
/Microcontroller/AT-BAT1-STAT2: R6.2, U1.32, U10.7
/Microcontroller/AT-BAT2-STAT1: R8.2, U1.23, U11.8
/Microcontroller/AT-BAT2-STAT2: R7.2, U1.12, U11.7
/Microcontroller/AT-RXD: U1.30, U9.1
/Microcontroller/AT-SCL: R3.2, U1.28, U4.10, U7.2, U8.3
/Microcontroller/AT-SDA: R4.2, U1.27, U4.9, U7.1, U8.4
/Microcontroller/AT-TXD: U1.31, U9.5
GND: B1.1, B2.1, C1.2, C2.2, C3.2, C4.2, C10.2, C13.2, C18.2, C19.2, C20.2, C21.2, C22.2, C23.2, C24.2, C25.2, C26.2, C26.3, C26.4, C27.2, C27.3, C27.4, C28.2, J1.6, P1.2, P2.4, P2.5, R12.2, R14.2, R15.2, R16.2, R25.1, R26.2, R27.2, R33.2, R35.2, R38.2, R39.2, R40.2, R41.2, R43.2, R45.2, R46.2, R47.2, U1.3, U1.5, U1.21, U2.4, U2.5, U3.4, U3.5, U4.3, U5.1, U5.4, U6.2, U7.4, U8.2, U9.7, U9.18, U9.21, U9.25, U9.26, U10.10, U10.11, U10.21, U11.10, U11.11, U11.21, U12.1, U12.2, U13.4, U14.1
unnamed: B1.2, U10.14, U10.15, U10.16
unnamed: B2.2, U11.14, U11.15, U11.16
unnamed: C2.1, U1.7, X1.1
unnamed: C4.1, U1.8, X1.4
unnamed: C5.1, R15.1, R17.1, U2.6
unnamed: C5.2, R17.2, U2.7, U4.4
unnamed: C6.1, R16.1, R18.1, U3.6
unnamed: C6.2, R18.2, U3.7, U4.7
unnamed: C20.1, U8.1
unnamed: C22.1, P2.3, R29.1
unnamed: C23.1, P2.2, R28.1
unnamed: C25.1, U9.17
unnamed: C26.1, C27.1, C28.1, U13.3, U14.4
unnamed: D1.1, U1.14
unnamed: D1.2, R10.2
unnamed: D3.1, U9.23
unnamed: D3.2, R30.2
unnamed: D4.1, U9.22
unnamed: D4.2, R31.2
unnamed: D5.2, U5.2
unnamed: FR1.2, P2.1
unnamed: J1.1, U1.16
unnamed: J1.3, U1.17
unnamed: J1.4, U1.15
unnamed: J1.5, R5.2, U1.29, U12.3, U12.4
unnamed: R6.1, U1.1
unnamed: R7.1, U1.13
unnamed: R8.1, U1.24
unnamed: R9.1, U1.26
unnamed: R11.2, R12.1, U4.5
unnamed: R13.2, R14.1, U4.6
unnamed: R25.2, U7.7
unnamed: R26.1, U7.6
unnamed: R27.1, U7.5
unnamed: R28.2, U9.16
unnamed: R29.2, U9.15
unnamed: R32.2, R33.1, U10.2
unnamed: R34.2, R35.1, U11.2
unnamed: R36.2, U10.6
unnamed: R37.2, U11.6
unnamed: R38.1, U10.12
unnamed: R39.1, U11.12
unnamed: R40.1, U10.13
unnamed: R41.1, U11.13
unnamed: R42.1, U10.5
unnamed: R42.2, R43.1, R46.1
unnamed: R44.1, U11.5
unnamed: R44.2, R45.1, R47.1
unnamed: U13.1, U14.2
unnamed: U13.2, U14.3

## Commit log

2015-05-17 Modified gitignore for KiCad (it was for Eagle), and updated the README
2015-05-17 Added 3D files, local libraries (Jesse's libraries), and the .pretty project files
    [TB.stl, TermB.stl, Terminalblock.scad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]
2015-05-17 Adding KiCad project
    [ADC.sch, BatteryManagement.sch, EnvSense.sch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]
2015-05-17 Added some previews of the PCB and updated the README
2015-07-13 Revision 2
    [$PWRREG.sch, ADC.sch, BatteryManagement.sch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]
2015-08-03 Updated hardware files from August 3 2015 Updated README
    [Mainboard.kicad_pcb, Mainboard.sch, PWRREG.sch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]
2015-08-16 Removed the TI battery management circuits and the LT power path management This was replaced with a microchip battery management IC to handle the power path management/load sharing and battery charg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
    [ADC.sch, BatteryCharging.sch, BatteryManagement.sch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]
2015-08-31 Produced Fabircation outputs Finished RevC of Main board Removed MPPT Board from Kicad Project
    [MPPT-B_Cu.gbl, MPPT-B_Mask.gbs, MPPT-B_SilkS.gbo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]
2015-08-31 Created third revison of the mainboard Created manufacturing files for the mainboard Deleated the MPPT board project
    [ADC.sch, BatteryCharging.sch, EnvSense.sch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]
2015-11-28 Revision 3 of Sentinal PCB major changes: - This is one PCB now - The MPPT circuitry has been taken off - Libraries have been moved around - The FTDI FT232R is being used - A buck boost regulator is 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
    [ADC.sch, BatteryCharging.sch, EnvSense.sch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]
2015-11-30 Rev 3.1 - Added microphone filter schematic and board - Added new silkscreen identifiers - Added Reset button for microcontroller - Fixed Address pin on ADS1015, pulled it up - Created new Fabricatio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
    [ADC.sch, BatteryCharging.sch, EnvSense.sch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]
2015-12-02 Edited JST footprints and updated board Small edits to READM
    [Mainboard-B_Cu.gbl, Mainboard-B_Mask.gbs, Mainboard-B_Paste.gbp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]
2015-12-07 Replaced DC-DC Switching circuit with a prebuilt module
    [ADC.sch, BatteryCharging.sch, EnvSense.sch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]
